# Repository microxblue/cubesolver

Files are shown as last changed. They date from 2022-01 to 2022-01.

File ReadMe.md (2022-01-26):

# Robotic Cube Solver #

This repo contains information on how to build a robotic cube solver using MCU STM32F103, stepper motors, servo and webcam.
Here is a video for a quick look.

https://user-images.githubusercontent.com/77249025/151071411-02db6310-b1c6-47c1-b3aa-7480b9b3eb15.mp4

## Hardware ##
The hardware platform is built with:
  - Host computer with webcam
  - TB6600 stepper motor driver x 3
  - 12HS4023 stepper motoir x 3
  - Servo (For example, SG90 Servo, or similar)
  - STM32F103 MCU board. (For example, BluePill STM32F103)
  - 3D printed parts (FreeCAD files: [X-shape](docs/XShape.FCStd), [Coupler](docs/Coupler.FCStd))

The system hardware wiring is listed in the diagram below:
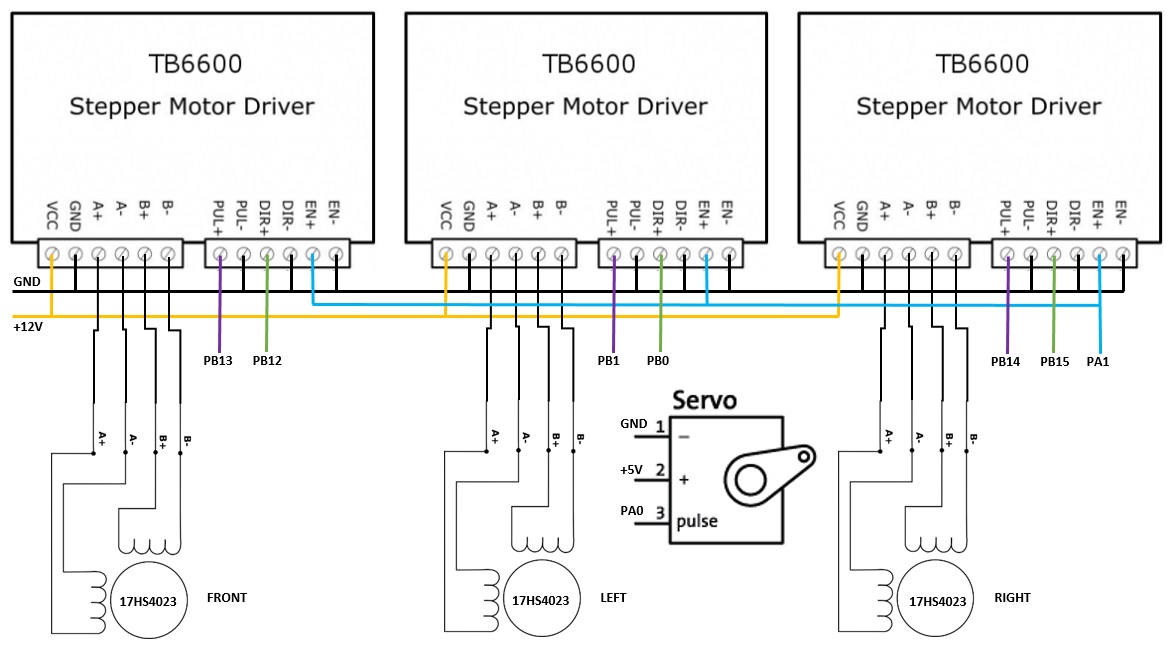
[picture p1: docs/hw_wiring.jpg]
Hardware Wring


### Firmware ###
STM32F103 firmware utilized the [STM32F1](https://github.com/microxblue/stm32f1) project.
Please follow the instruction there to build Shell and run CmdCube Module. Once the module
is launched, the following key stroke in shell console can test the stepper and servo.
  - 'w': servo lift the arm
  - 'q': servo put down the arm
  - 'x': cube rotate 90 degree
  - 'y': cube rotate -90 degree
  - 'u': left face rotate 90 degree
  - 'v': left face rotate -90 degree
  - 's': right face rotate 90 degree
  - 't': right face rotate -90 degree

### Host Software ###
Python 3 script is used on host to scan the rublik's cube faces and find solutions for it.
It utilizes OPENCV to extract the rublik's cube colors, and use Kociemba two stage algorithm
to find a solution.
It is required to install some python modules:

    python -m pip install -r requirements.txt

To run the script:

    python cubesolver.py

### Setup ###
Please follow the following steps for setup:
  - Setup the hardware as shown in the diagram.
  - Mount rublk cube to the stepper motors.
    - White center piece should face towards left side stepper motor, and yellow center piece should face towards right side stepper motor
    - Orange center piece should face up
  - Install Servo so that:
    - It should block the middle column from rotating when the arm is up.
    - It should allow the free whole cube rotation when the arm is down.
  - Power up the stepper motor, servo and STM32 MCU.
  - Run CmdCube module:

        cd Module
        make run MOD=CmdCube
  - Launch cubesolver:

        python  cubesolver.py
  - Adjust cam position so that
    - The cube front face can exactly fit in the blue rectangle.
  - Issue commands as needed:
    - Press 'n' in the webcam window to scramble the cube.
    - Press 'd' in the webcam window to scan the cube faces.
    - Press 'm' in the webcam window to resolve the cube.
    - Press 'x' in the webcam window to quit.

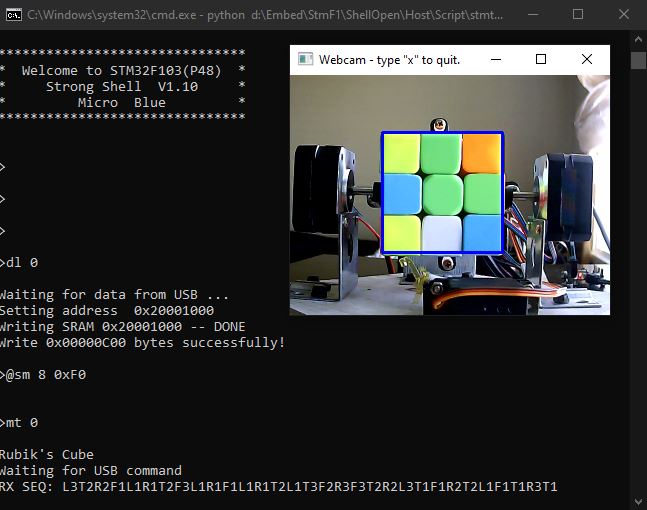
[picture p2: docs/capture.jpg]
Host Screenshot Host screenshot


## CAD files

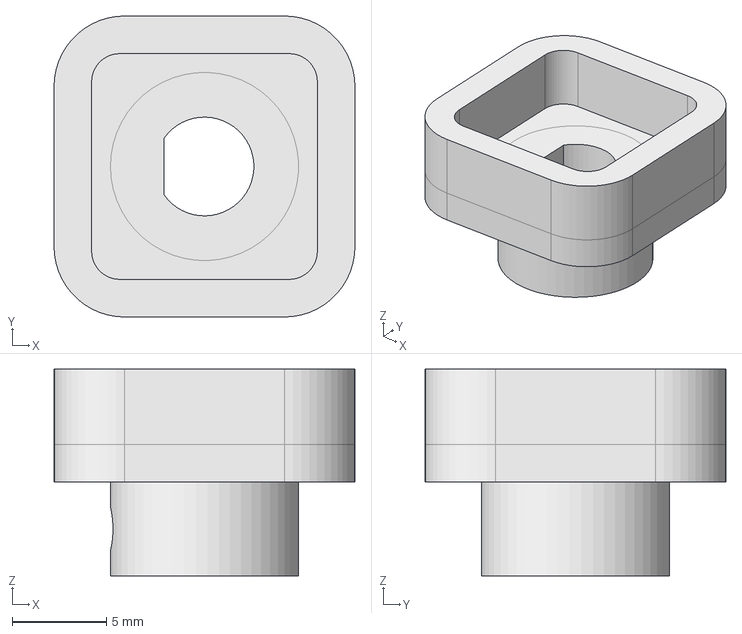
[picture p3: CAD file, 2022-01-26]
docs/Coupler.FCStd
16.0 x 16.0 x 11.0 mm

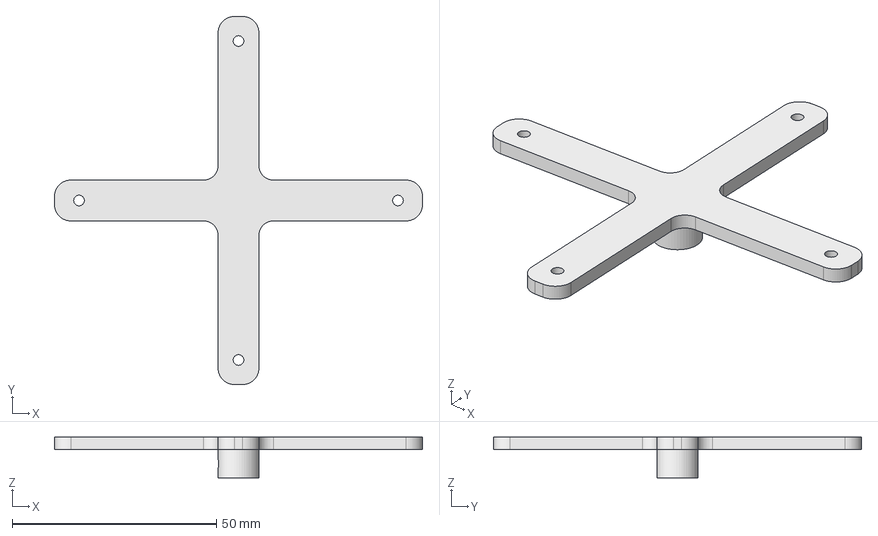
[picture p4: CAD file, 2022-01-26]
docs/XShape.FCStd
90.0 x 90.0 x 10.0 mm

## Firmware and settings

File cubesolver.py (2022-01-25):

import os
import sys
import time
import argparse
import usb.core
import usb.util
import cv2
import math
import random
import numpy as np
import kociemba

class STM32_USB_DEV:

    MAX_PKT      = 64
    CMD_PKT_LEN  = 12

    MY_VID  = 0x0686
    MY_PID  = 0x1023

    def __init__(self, devaddr, product, interface = 0):
        # find our device
        self.dev    = None
        self.infidx = None
        self.epout  = None
        self.epin   = None

        devs = usb.core.find(idVendor=STM32_USB_DEV.MY_VID,
                             idProduct=product,
                             find_all=True)

        if interface:
            infnum = 1
        else:
            infnum = 0

        tgts = []
        for dev in devs:
            cfg = next(iter(dev), None)
            infidx = 0
            for inf in iter(cfg):
                if inf.bInterfaceNumber == infnum:
                    tgts.append((dev, infidx))
                infidx = infidx + 1

        if len(tgts) > 0:
            if devaddr == '?':
                # list all devices
                for idx, tgt in enumerate(tgts):
                    print ('Device %d (%04X:%04X) at address %d' % (idx, tgt[0].idVendor, tgt[0].idProduct, tgt[0].address))
                sys.exit (-1)
            elif devaddr == '':
                self.dev, self.infidx = tgts[0]
            else:
                if devaddr.startswith('0x'):
                    addr = int(devaddr, 16)
                else:
                    addr = int(devaddr)
                for dev, infidx in tgts:
                    if dev.address == addr:
                        self.dev = dev
                        self.infidx = infidx

        if self.dev is None:
            raise SystemExit  ('Cannot find matched StmUsb device!')

        # set the active configuration. With no arguments, the first
        # configuration will be the active one
        if sys.platform == "win32":
            self.dev.set_configuration()

        # get an endpoint instance
        self.cfg  = self.dev.get_active_configuration()
        self.intf = self.cfg[(self.infidx, 0)]

        self.epout = usb.util.find_descriptor(
            self.intf,
            # match the first OUT endpoint
            custom_match=
            lambda e: usb.util.endpoint_direction(e.bEndpointAddress) == usb.util.ENDPOINT_OUT)

        self.epin = usb.util.find_descriptor(
            self.intf,
            # match the first OUT endpoint
            custom_match=
            lambda e: usb.util.endpoint_direction(e.bEndpointAddress) == usb.util.ENDPOINT_IN)

        if self.epout is None or self.epin is None:
            raise SystemExit ('Cannot find End Point!')



    def read (self, length = MAX_PKT, timeout = 100):
        try:
            data = self.dev.read(self.epin, length, timeout)
        except usb.USBError as e:
            err_str = repr(e)
            if ('timeout error' in err_str) or ('timed out' in err_str):
                data = b''
            else:
                data = None
        return data

    def write (self, data, timeout = 100):
        try:
            ret = self.dev.write(self.epout, data)
        except usb.USBError as e:
            if 'timeout error' in repr(e):
                ret = 0
            else:
                raise SystemExit ('\n%s' % repr(e))
        return len(data)

    def send_cmd (self, cmd):
        if len(cmd) <= STM32_USB_DEV.CMD_PKT_LEN:
            data = cmd + b'\x00' * (STM32_USB_DEV.CMD_PKT_LEN - len(cmd))
            self.write (data)

    def send_dat (self, dat):
        if len(dat) <= STM32_USB_DEV.MAX_PKT:
            data = dat + b'\x00' * (STM32_USB_DEV.MAX_PKT - len(dat))
            self.write (data)

    def close (self):
        usb.util.dispose_resources(self.dev)
        self.dev.reset()


def get_dominant_color(roi):
    average = roi.mean(axis=0).mean(axis=0)
    pixels = np.float32(roi.reshape(-1, 3))

    n_colors = 1
    criteria = (cv2.TERM_CRITERIA_EPS + cv2.TERM_CRITERIA_MAX_ITER, 200, .1)
    flags = cv2.KMEANS_RANDOM_CENTERS
    _, labels, palette = cv2.kmeans(pixels, n_colors, None, criteria, 10, flags)
    _, counts = np.unique(labels, return_counts=True)
    dominant = palette[np.argmax(counts)]
    return tuple(dominant.astype(np.uint8))


def color_sample (bgrcap, cam_box):
    x,y,w,h = cam_box
    s = 4
    clrs = []
    for j in range (3):
        for i in range (3):
            x1, y1 = (int(x + w*i/3 + w/6), int(y + h*j/3 + h/6))
            roi = bgrcap[y1-4:y1+4, x1-4:x1+4]
            ret = get_dominant_color (roi)
            clrs.append (ret)
    if len(clrs) == 9:
        return (clrs)
    else:
        return []


def color_diff (color_set, color_tst):
    # calculate distance between test color and the full set
    gap = []
    for each in color_set:
        gap.append (np.linalg.norm(each - color_tst))
    return gap


def color_classify (color_set, threshold):
    # flag
    color_res = [0] * color_set.shape[0]

    # group colors using the distance
    clr_grp = 1
    while True:
        if 0 not in color_res:
            break
        else:
            idx = color_res.index(0)
        gaps = color_diff (color_set, color_set[idx])
        for idx, gap in enumerate(gaps):
            if gap < threshold and color_res[idx] == 0:
                color_res[idx] = clr_grp
        clr_grp += 1

    return color_res
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
